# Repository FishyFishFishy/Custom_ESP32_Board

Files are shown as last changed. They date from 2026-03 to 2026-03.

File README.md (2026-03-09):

# Custom_ESP32_Board
Making a custom ESP32 Board for generic use

After making my devboard with an RP2040, I wanted to have something with an ESP32 MCU. I want to use this for general purpose projects that need additional wifi/bluetooth support. In particular, I want to make some automated window blinds and a one handed soldering tool, so I am using this as a stepping stone to learn this pcb design.

This board has a USB Type-C port to flash and power it.

Schematic:
Screenshot 2026-03-09 at 4 56 26 PM

PCB Layout:
Screenshot 2026-03-09 at 4 56 17 PM

3D Model:
Screenshot 2026-03-09 at 4 56 44 PM

BOM:
| Item Description | Supplier | Supplier Part # | Mfr Part # | Qty | Unit Price | Extended Price |
| :--- | :--- | :--- | :--- | :--- | :--- | :--- |
| CAP CER 10UF 25V X5R 0805 | DigiKey | 1276-6454-1-ND | CL21A106KAYNNNG | 35 | $0.08900 | $3.12 |
| CAP CER 1UF 16V X5R 0603 | DigiKey | 1276-1034-1-ND | CL10A105KO8NNNC | 10 | $0.03100 | $0.31 |
| RES 10K OHM 1% 1/8W 0603 | DigiKey | RNCP0603FTD10K0CT-ND | RNCP0603FTD10K0 | 40 | $0.01080 | $0.43 |
| CAP CER 0.1UF 50V X7R 0603 | DigiKey | 1276-CL10B104KB8NNNLCT-ND | CL10B104KB8NNNL | 50 | $0.01800 | $0.90 |
| IC REG LINEAR 3.3V 1A SOT-223-3L | DigiKey | 4518-AMS1117-3.3CT-ND | AMS1117-3.3 | 10 | $0.20000 | $2.00 |
| CAP CER 22PF 50V C0G/NP0 0603 | DigiKey | 399-C0603C220J5GACTUCT-ND | C0603C220J5GACTU | 10 | $0.06900 | $0.69 |
| SWITCH TACTILE SPST-NO 0.05A 16V | DigiKey | CKN10504CT-ND | PTS810SJG250SMTR LFS | 20 | $0.50700 | $10.14 |
| LED BLUE CLEAR CHIP SMD | DigiKey | 160-1646-1-ND | LTST-C190TBKT | 10 | $0.09400 | $0.94 |
| RF TXRX MOD BT WIFIU.FL SMD | DigiKey | 1965-ESP32-S3-WROOM-1U-N16R8CT-ND | ESP32-S3-WROOM-1U-N16R8 | 5 | $6.56000 | $32.80 |
| RF TXRX MOD BT WIFI PCB TH SMD | DigiKey | 5407-ESP32-C3-MINI-1-H4CT-ND | ESP32-C3-MINI-1-H4 | 5 | $3.28000 | $16.40 |
| 1N5819HW-7-F (Diode 40V 1A SOD-123) | LCSC | C82544 | 1N5819HW-7-F | 20 | $0.0295 | $0.59 |
| SK6812 LED Addressable SMD-4P | LCSC | C5378720 | SK6812 | 10 | $0.0870 | $0.87 |
| 5.1kΩ ±0.1% 125mW 0805 Ceramic Resistor | LCSC | C2912598 | HoAR0805-1/8W-5.1KR-0.1% | 20 | $0.0776 | $1.55 |
| 200Ω ±0.1% 130mW 0805 Thin Film Resistor| LCSC | C2849095 | PTFR0805B200RP9 | 10 | $0.0733 | $0.73 |
| USB-C Receptacle 16-Pin Right Angle | LCSC | C2765186 | TYPE-C 16PIN 2MD(073) | 20 | $0.0615 | $1.23 |
| ESD5B5.0ST1G ESD Protection | LCSC | C93623 | ESD5B5.0ST1G | 40 | $0.0362 | $1.45 |

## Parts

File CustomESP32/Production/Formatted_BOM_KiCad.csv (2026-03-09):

Reference | Value | Footprint | Quantity | Manufacturer | MPN | Supplier | Supplier Part # | Description
 | LESD5D5.0CT1G | SOD-523 | 6 | LRC | LESD5D5.0CT1G | LCSC | C383211 | Zener Diode 5.6V 18.6V 5V Bi-Directional SOD-523 ESD Protection Devices ROHS
 | 1N5819HW-7-F | SOD-123 | 2 | Diodes Incorporated | 1N5819HW-7-F | LCSC | C82544 | Diode 40V 450mV@1A 1A SOD-123 Schottky Barrier Diodes (SBD) ROHS
 | SK6812 | SMD-4P,5.4x5mm | 2 | OPSCO Optoelectronics | SK6812 | LCSC | C5378720 | SMD-4P,5.4x5mm Light Emitting Diodes (LED) ROHS
 | HoAR0805-1/8W-5.1KR-0.1%-TCR25 | 805 | 4 | Milliohm | HoAR0805-1/8W-5.1KR-0.1%-TCR25 | LCSC | C2912598 | 5k1 Resistor 125mW Ceramic resistor ±25ppm/℃ ±0.1% 5.1kΩ 0805 Chip Resistor - Surface Mount ROHS
 | PTFR0805B200RP9 | 805 | 2 | Resistor.Today | PTFR0805B200RP9 | LCSC | C2849095 | 200ohm Resistor 0.13W Thin Film Resistor ±25ppm/℃ ±0.1% 200Ω 0805 Chip Resistor - Surface Mount ROHS
 | TYPE-C 16PIN 2MD(073) | SMD | 2 | SHOU HAN | TYPE-C 16PIN 2MD(073) | LCSC | C2765186 | USB-C Connector 5A 1 Surface Mount 16P Female -25℃~+85℃ Type-C SMD USB Connectors ROHS
 | CL21A106KAYNNNG | 0805 | 7 |  | CL21A106KAYNNNG | DigiKey | 1276-6454-1-ND | 10uF/25V Capacitor CAP CER 10UF 25V X5R 0805
 | CL10A105KO8NNNC | 0603 | 2 |  | CL10A105KO8NNNC | DigiKey | 1276-1034-1-ND | 1uF/16V Capacitor CAP CER 1UF 16V X5R 0603
 | RNCP0603FTD10K0 | 0603 | 8 |  | RNCP0603FTD10K0 | DigiKey | RNCP0603FTD10K0CT-ND | 10kohm Resistor RES 10K OHM 1% 1/8W 0603
 | CL10B104KB8NNNL | 0603 | 10 |  | CL10B104KB8NNNL | DigiKey | 1276-CL10B104KB8NNNLTR-ND | CAP CER 0.1UF 50V X7R 0603
 | AMS1117-3.3 | SOT223 | 2 |  | AMS1117-3.3 | DigiKey | 4518-AMS1117-3.3TR-ND | IC LDO REG 3.3V 1A SOT223
 | C0603C220J5GAC7867 | 0603 | 2 |  | C0603C220J5GAC7867 | DigiKey | 399-C0603C220J5GAC7867TR-ND | CAP CER 22PF 50V C0G/NP0 0603
 | PTS810 SJG 250 SMTR LFS |  | 4 |  | PTS810 SJG 250 SMTR LFS | DigiKey | CKN10504TR-ND | SWITCH TACTILE SPST-NO 0.05A 16V
 | LTST-C190TBKT | SMD | 2 |  | LTST-C190TBKT | DigiKey | 160-1646-2-ND | BLUE RED CLEAR CHIP SMD
 | ESP32-S3-WROOM-1U-N16R8 | SMD | 1 |  | ESP32-S3-WROOM-1U-N16R8 | DigiKey | 1965-ESP32-S3-WROOM-1U-N16R8TR-ND | RF TXRX MOD BLUETOOTH U.FL SMD
 | ESP32-C3-MINI-1-H4 | SMD | 1 |  | ESP32-C3-MINI-1-H4 | DigiKey | 1965-ESP32-C3-MINI-1-H4TR-ND | RF TXRX MODULE BT PCB TRACE SMD

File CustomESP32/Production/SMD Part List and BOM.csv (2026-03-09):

 | From LCSC
Order Qty. | LCSC Part Number | Manufacture Part Number | Manufacturer | Package | Description | RoHS | Unit Price
6 | C383211 | LESD5D5.0CT1G | LRC | SOD-523 | Zener Diode 5.6V 18.6V 5V Bi-Directional SOD-523 ESD Protection Devices ROHS | YES | 0.0152
2 | C82544 | 1N5819HW-7-F | Diodes Incorporated | SOD-123 | Diode 40V 450mV@1A 1A SOD-123 Schottky Barrier Diodes (SBD) ROHS | YES | 0.0208
2 | C5378720 | SK6812 | OPSCO Optoelectronics | SMD-4P,5.4x5mm | SMD-4P,5.4x5mm Light Emitting Diodes (LED) ROHS | YES | 0.153
4 | C2912598 | HoAR0805-1/8W-5.1KR-0.1%-TCR25 | Milliohm | 805 | 5k1 Resistor 125mW Ceramic resistor ±25ppm/℃ ±0.1% 5.1kΩ 0805 Chip Resistor - Surface Mount ROHS | YES | 0.0506
2 | C2849095 (Used these instead of the 75 and 110ohm resistors, but its flexible so long as it�s the value or greater) | PTFR0805B200RP9 | Resistor.Today | 805 | 200ohm Resistor 0.13W Thin Film Resistor ±25ppm/℃ ±0.1% 200Ω 0805 Chip Resistor - Surface Mount ROHS | YES | 0.1403
2 | C2765186 | TYPE-C 16PIN 2MD(073) | SHOU HAN | SMD | USB-C Connector 5A 1 Surface Mount 16P Female -25℃~+85℃ Type-C SMD USB Connectors ROHS | YES | 0.0523
 | From DigiKey
 | Digi-Key Part # | Manufacturer Part Number | Description | Backorder | Unit Price
7 | 1276-6454-1-ND | CL21A106KAYNNNG | 10uF/25V Capacitor CAP CER 10UF 25V X5R 0805 | 0 | $0.07
2 | 1276-1034-1-ND | CL10A105KO8NNNC | 1uF/16V Capacitor CAP CER 1UF 16V X5R 0603 | 0 | $0.01
8 | RNCP0603FTD10K0CT-ND | RNCP0603FTD10K0 | 10kohm Resistor RES 10K OHM 1% 1/8W 0603 | 0 | $0.02
10 | 1276-CL10B104KB8NNNLTR-ND | CL10B104KB8NNNL | CAP CER 0.1UF 50V X7R 0603 | 0 | $0.10
2 | 4518-AMS1117-3.3TR-ND | AMS1117-3.3 | IC LDO REG 3.3V 1A SOT223 | 0 | $0.48
2 | 399-C0603C220J5GAC7867TR-ND | C0603C220J5GAC7867 | CAP CER 22PF 50V C0G/NP0 0603 | 0 | $0.14
4 | CKN10504TR-ND | PTS810 SJG 250 SMTR LFS | SWITCH TACTILE SPST-NO 0.05A 16V | 0 | $0.55
2 | 160-1646-2-ND | LTST-C190TBKT | BLUE RED CLEAR CHIP SMD | 0 | $0.35
1 | 1965-ESP32-S3-WROOM-1U-N16R8TR-ND | ESP32-S3-WROOM-1U-N16R8 | RF TXRX MOD BLUETOOTH U.FL SMD | 0 | $3.90
1 | 1965-ESP32-C3-MINI-1-H4TR-ND | ESP32-C3-MINI-1-H4 | RF TXRX MODULE BT PCB TRACE SMD | 0 | $1.90
 | ALL OTHER COMPONENTS WERE PURCHASED VIA AMAZON. Remember, it's better to buy too many than too few.
 | (Links in the project BOM www.roboticworx.io)

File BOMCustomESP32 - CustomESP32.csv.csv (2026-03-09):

Item Description | Supplier | Supplier Part # | Mfr Part # | Qty | Unit Price | Extended Price
CAP CER 10UF 25V X5R 0805 | DigiKey | 1276-6454-1-ND | CL21A106KAYNNNG | 35 | $0.09 | $3.12
CAP CER 1UF 16V X5R 0603 | DigiKey | 1276-1034-1-ND | CL10A105KO8NNNC | 10 | $0.03 | $0.31
RES 10K OHM 1% 1/8W 0603 | DigiKey | RNCP0603FTD10K0CT-ND | RNCP0603FTD10K0 | 40 | $0.01 | $0.43
CAP CER 0.1UF 50V X7R 0603 | DigiKey | 1276-CL10B104KB8NNNLCT-ND | CL10B104KB8NNNL | 50 | $0.02 | $0.90
IC REG LINEAR 3.3V 1A SOT-223-3L | DigiKey | 4518-AMS1117-3.3CT-ND | AMS1117-3.3 | 10 | $0.20 | $2.00
CAP CER 22PF 50V C0G/NP0 0603 | DigiKey | 399-C0603C220J5GACTUCT-ND | C0603C220J5GACTU | 10 | $0.07 | $0.69
SWITCH TACTILE SPST-NO 0.05A 16V | DigiKey | CKN10504CT-ND | PTS810SJG250SMTR LFS | 20 | $0.51 | $10.14
LED BLUE CLEAR CHIP SMD | DigiKey | 160-1646-1-ND | LTST-C190TBKT | 10 | $0.09 | $0.94
RF TXRX MOD BT WIFIU.FL SMD | DigiKey | 1965-ESP32-S3-WROOM-1U-N16R8CT-ND | ESP32-S3-WROOM-1U-N16R8 | 5 | $6.56 | $32.80
RF TXRX MOD BT WIFI PCB TH SMD | DigiKey | 5407-ESP32-C3-MINI-1-H4CT-ND | ESP32-C3-MINI-1-H4 | 5 | $3.28 | $16.40
1N5819HW-7-F (Diode 40V 1A SOD-123) | LCSC | C82544 | 1N5819HW-7-F | 20 | $0.03 | $0.59
SK6812 LED Addressable SMD-4P | LCSC | C5378720 | SK6812 | 10 | $0.09 | $0.87
5.1kΩ ±0.1% 125mW 0805 Ceramic Resistor | LCSC | C2912598 | HoAR0805-1/8W-5.1KR-0.1% | 20 | $0.08 | $1.55
200Ω ±0.1% 130mW 0805 Thin Film Resistor | LCSC | C2849095 | PTFR0805B200RP9 | 10 | $0.07 | $0.73
USB-C Receptacle 16-Pin Right Angle | LCSC | C2765186 | TYPE-C 16PIN 2MD(073) | 20 | $0.06 | $1.23
ESD5B5.0ST1G ESD Protection | LCSC | C93623 | ESD5B5.0ST1G | 40 | $0.04 | $1.45

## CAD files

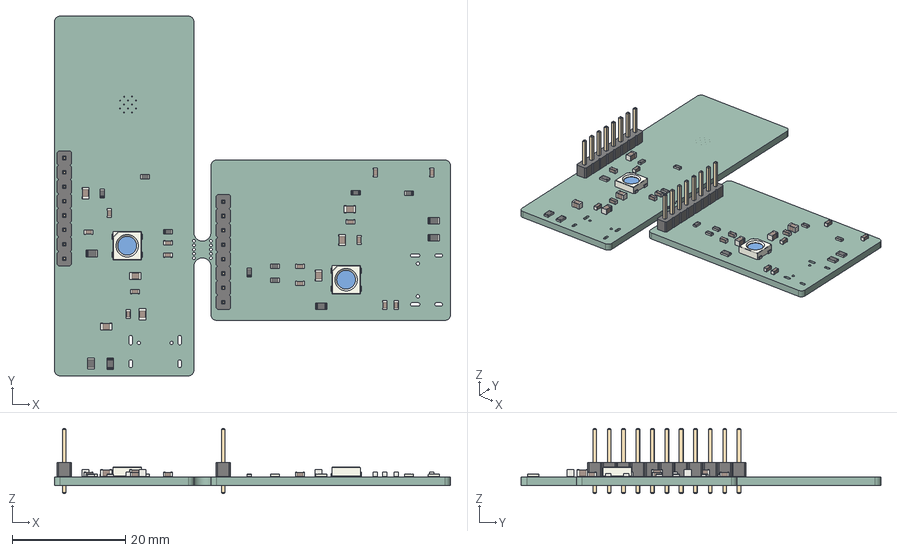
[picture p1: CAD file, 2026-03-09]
CustomESP32/Production/CustomESP32.step
70.0 x 63.6 x 11.5 mm
R_0805_2012Metric x 6
C_0603_1608Metric x 14
C_0805_2012Metric x 7
R_0603_1608Metric x 8
PinHeader_1x08_P2.54mm_Vertical x 2
LED_SK6812_PLCC4_5.0x5.0mm_P3.2mm x 2
CustomESP32_PCB

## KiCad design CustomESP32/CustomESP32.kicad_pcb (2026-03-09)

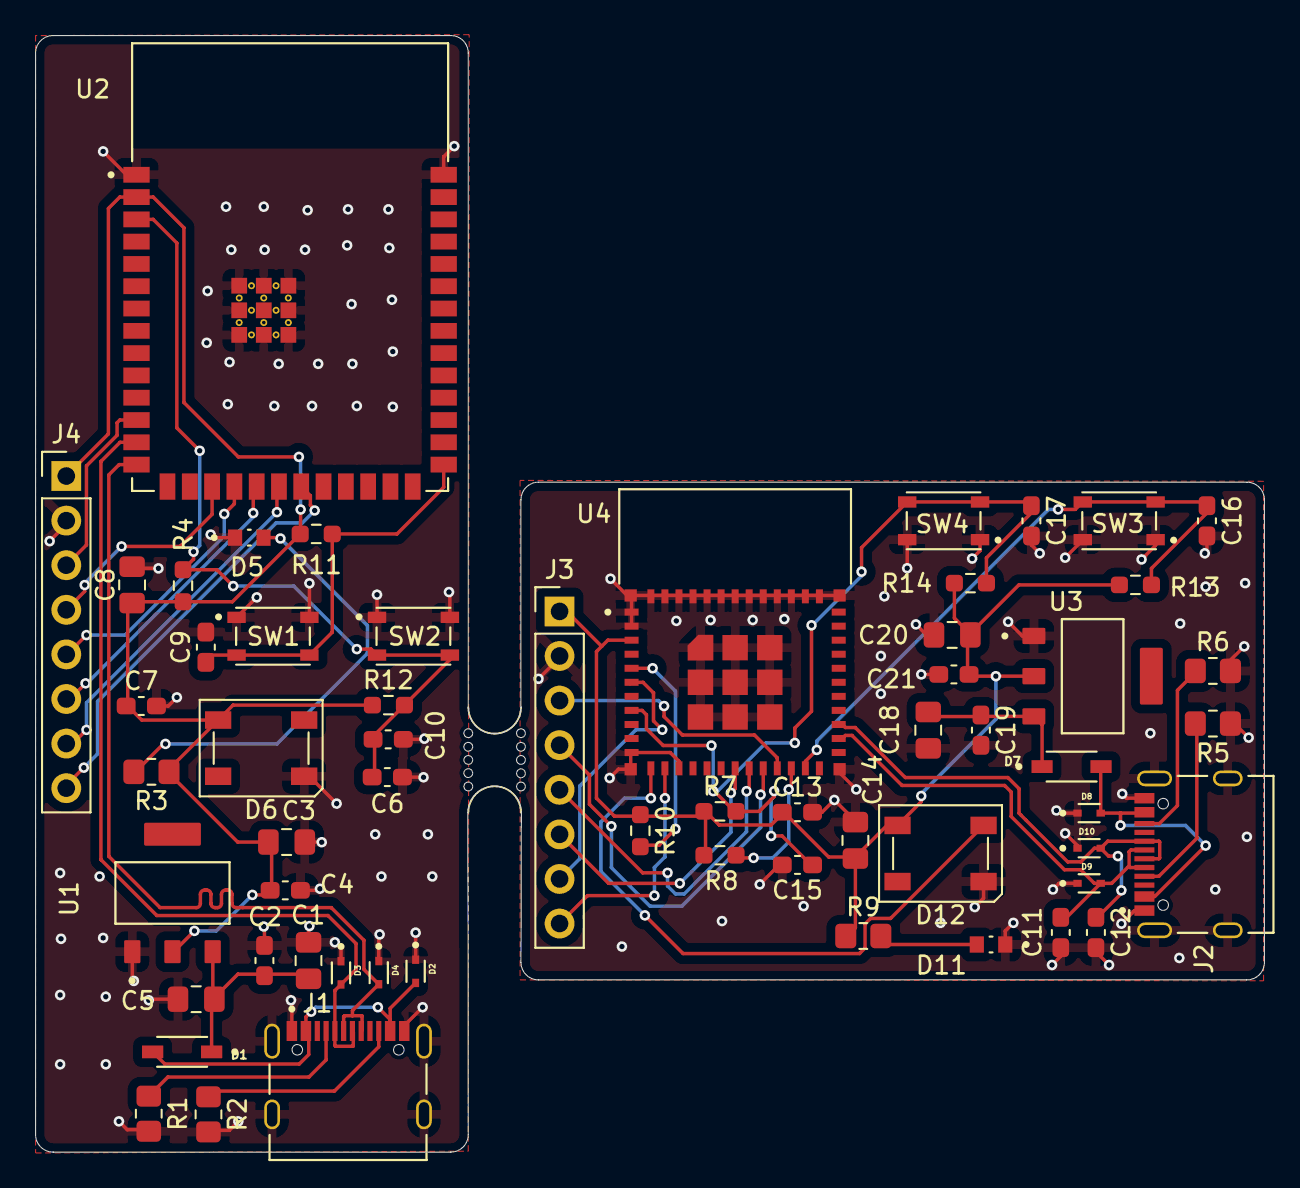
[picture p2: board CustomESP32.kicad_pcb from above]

Board: 2 copper layers, 70.0 x 63.6 mm, 60 parts (0 on the bottom side), 35 nets.

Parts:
C1, C3, C5, C8, C14, C18, C20: 10uF; C_0805_2012Metric_Pad1.18x1.45mm_HandSolder
C2, C4, C7, C9, C10, C13, C16, C17, C19, C21: 0u1F; C_0603_1608Metric_Pad1.08x0.95mm_HandSolder
C6, C15: 1uF; C_0603_1608Metric_Pad1.08x0.95mm_HandSolder
C11, C12: 22pF; C_0603_1608Metric_Pad1.08x0.95mm_HandSolder
D1, D7: 1N5819HW-7-F; SOD3715X145N
D2, D3, D4, D8, D9, D10: LESD5D5.0CT1G; TVS_LESD5D5.0CT1G
D5, D11: LTST-C190KGKT; LEDC1608X35N
D6, D12: SK6812; LED_SK6812_PLCC4_5.0x5.0mm_P3.2mm
J1, J2: TYPE-C-31-M-12; HRO_TYPE-C-31-M-12
J3: TFTLCDC3; PinHeader_1x08_P2.54mm_Vertical
J4: TFTLCDS3; PinHeader_1x08_P2.54mm_Vertical
R1, R2, R5, R6: 5k1; R_0805_2012Metric_Pad1.20x1.40mm_HandSolder
R3, R9: 75; R_0805_2012Metric_Pad1.20x1.40mm_HandSolder
R4, R7, R8, R10, R11, R12, R13, R14: 10k; R_0603_1608Metric_Pad0.98x0.95mm_HandSolder
SW1, SW2, SW3, SW4: PTS810_SJM_250_SMTR_LFS; SW_PTS810_SJM_250_SMTR_LFS
U1, U3: AMS1117-3.3; SOT229P700X180-4N
U2: ESP32-S3-WROOM-1-N16R2; XCVR_ESP32-S3-WROOM-1-N16R2
U4: ESP32-C3-MINI-1-N4; XCVR_ESP32-C3-MINI-1-N4
mouse-bite-3mm-slot: VAL**; mouse-bite-3mm-slot

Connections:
BL: J4.8, U2.21 (IO13)
BL(2): J3.8, U4.13 (IO1)
CHIP_PU: C6.1, C10.1, R4.2, R12.2, SW2.3, SW2.4, U2.3 (EN)
CHIP_PU(2): C15.1, C17.1, R7.2, R14.2, SW4.3, SW4.4, U4.8 (EN)
CLK: J4.4, U2.17 (IO9)
CLK(2): J3.4, U4.20 (IO6)
CS: J4.5, U2.18 (IO10)
CS(2): J3.5, U4.19 (IO5)
D2+: C12.1, D10.2, J2.A6 (DP1), J2.B6 (DP2), U4.27 (IO19)
D2-: C11.1, D9.2, J2.A7 (DN1), J2.B7 (DN2), U4.26 (IO18)
D+: D4.2, J1.A6 (DP1), J1.B6 (DP2), U2.14 (IO20)
D-: D3.2, J1.A7 (DN1), J1.B7 (DN2), U2.13 (IO19)
DC: J4.6, U2.19 (IO11)
DC(2): J3.6, U4.18 (IO4)
DIN: J4.3, U2.12 (IO8)
DIN(2): J3.3, U4.21 (IO7)
ESP_3V3: C3.1, C4.1, C7.1, C8.1, D6.3 (VDD), J4.1, R3.1, R4.1, R11.1, R12.1, U1.2 (VOUT), U2.2 (3V3)
ESP_3V3(2): C13.1, C14.1, C20.1, C21.1, D12.3 (VDD), J3.1, R7.1, R8.1, R9.1, R10.1, R13.1, R14.1, U3.2 (VOUT), U4.3 (3V3)
GND: C1.2, C2.2, C3.2, C4.2, C5.2, C6.2, C7.2, C8.2, C9.2, C10.2, C11.2, C12.2, C13.2, C14.2, C15.2, C16.2, C17.2, C18.2, C19.2, C20.2, C21.2, D2.1, D3.1, D4.1, D5.C, D6.1 (VSS), D8.1, D9.1, D10.1, D11.C, D12.1 (VSS), J1.A1_B12 (GND), J1.B1_A12 (GND), J1.S1 (SHIELD), J1.S2 (SHIELD), J1.S3 (SHIELD), J1.S4 (SHIELD), J2.A1_B12 (GND), J2.B1_A12 (GND), J2.S1 (SHIELD), J2.S2 (SHIELD), J2.S3 (SHIELD), J2.S4 (SHIELD), J3.2, J4.2, R1.2, R2.2, R5.2, R6.2, SW1.1, SW1.2, SW2.1, SW2.2, SW3.1, SW3.2, SW4.1, SW4.2, U1.1 (GND/ADJ), U2.1 (GND), U2.40 (GND), U2.41_1 (GND), U2.41_2 (GND), U2.41_3 (GND), U2.41_4 (GND), U2.41_5 (GND), U2.41_6 (GND), U2.41_7 (GND), U2.41_8 (GND), U2.41_9 (GND), U3.1 (GND/ADJ), U4.1 (GND), U4.2 (GND), U4.11 (GND), U4.14 (GND), U4.36 (GND), U4.37 (GND), U4.38 (GND), U4.39 (GND), U4.40 (GND), U4.41 (GND), U4.42 (GND), U4.43 (GND), U4.44 (GND), U4.45 (GND), U4.46 (GND), U4.47 (GND), U4.48 (GND), U4.49_1 (GND), U4.49_2 (GND), U4.49_3 (GND), U4.49_4 (GND), U4.49_5 (GND), U4.49_6 (GND), U4.49_7 (GND), U4.49_8 (GND), U4.49_9 (GND), U4.50 (GND), U4.51 (GND), U4.52 (GND), U4.53 (GND)
GPIO0: C9.1, R11.2, SW1.3, SW1.4, U2.27 (IO0)
GPIO9: C16.1, R13.2, SW3.3, SW3.4, U4.23 (IO9)
unnamed: D5.A, R3.2
unnamed: D11.A, R9.2
unnamed: J1.A5 (CC1), R1.1
unnamed: J1.B5 (CC2), R2.1
unnamed: J2.A5 (CC1), R5.1
unnamed: J2.B5 (CC2), R6.1
unnamed: R10.2, U4.5 (IO2)
unnamed: R8.2, U4.22 (IO8)
RGB(2): D12.2 (DIN), U4.12 (IO0)
RST: J4.7, U2.20 (IO12)
RST(2): J3.7, U4.6 (IO3)
VBUS: D1.A, D2.2, D7.A, D8.2, J1.A4_B9 (VBUS), J1.B4_A9 (VBUS), J2.A4_B9 (VBUS), J2.B4_A9 (VBUS)
VCC_5V: C1.1, C2.1, C5.1, D1.C, U1.3 (VIN)
VCC_5V(2): C18.1, C19.1, D7.C, U3.3 (VIN)

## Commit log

2026-03-09 Enhance README with project details and images
    Added project description and images for schematic, PCB layout, and 3D model.
2026-03-09 Add BOM section to README
    Added Bill of Materials (BOM) section with component details.
